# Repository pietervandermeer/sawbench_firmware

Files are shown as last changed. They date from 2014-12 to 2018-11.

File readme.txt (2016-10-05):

The Sawbench Synthesizer firmware.

(c) Tasty Chips Electronics, 2014-2016

This code may be used to update your sawbench synth, using only an Arduino Uno 
(10 euro from China). The easiest way of doing things is to: 

1) install this archive in your arduino folder. On Mac that's mostly 
~/Documents/Arduino

2) start Arduino IDE

3) open sawbench_v3/sawbench_v3.ino

4) attach your arduino uno

5) upload. The firmware is now present on the Arduino's Atmega328P. 

6) open up the sawbench, and remove its atmega. 

7) replace the sawbench's Atmega with the one from the Arduino. Presto!

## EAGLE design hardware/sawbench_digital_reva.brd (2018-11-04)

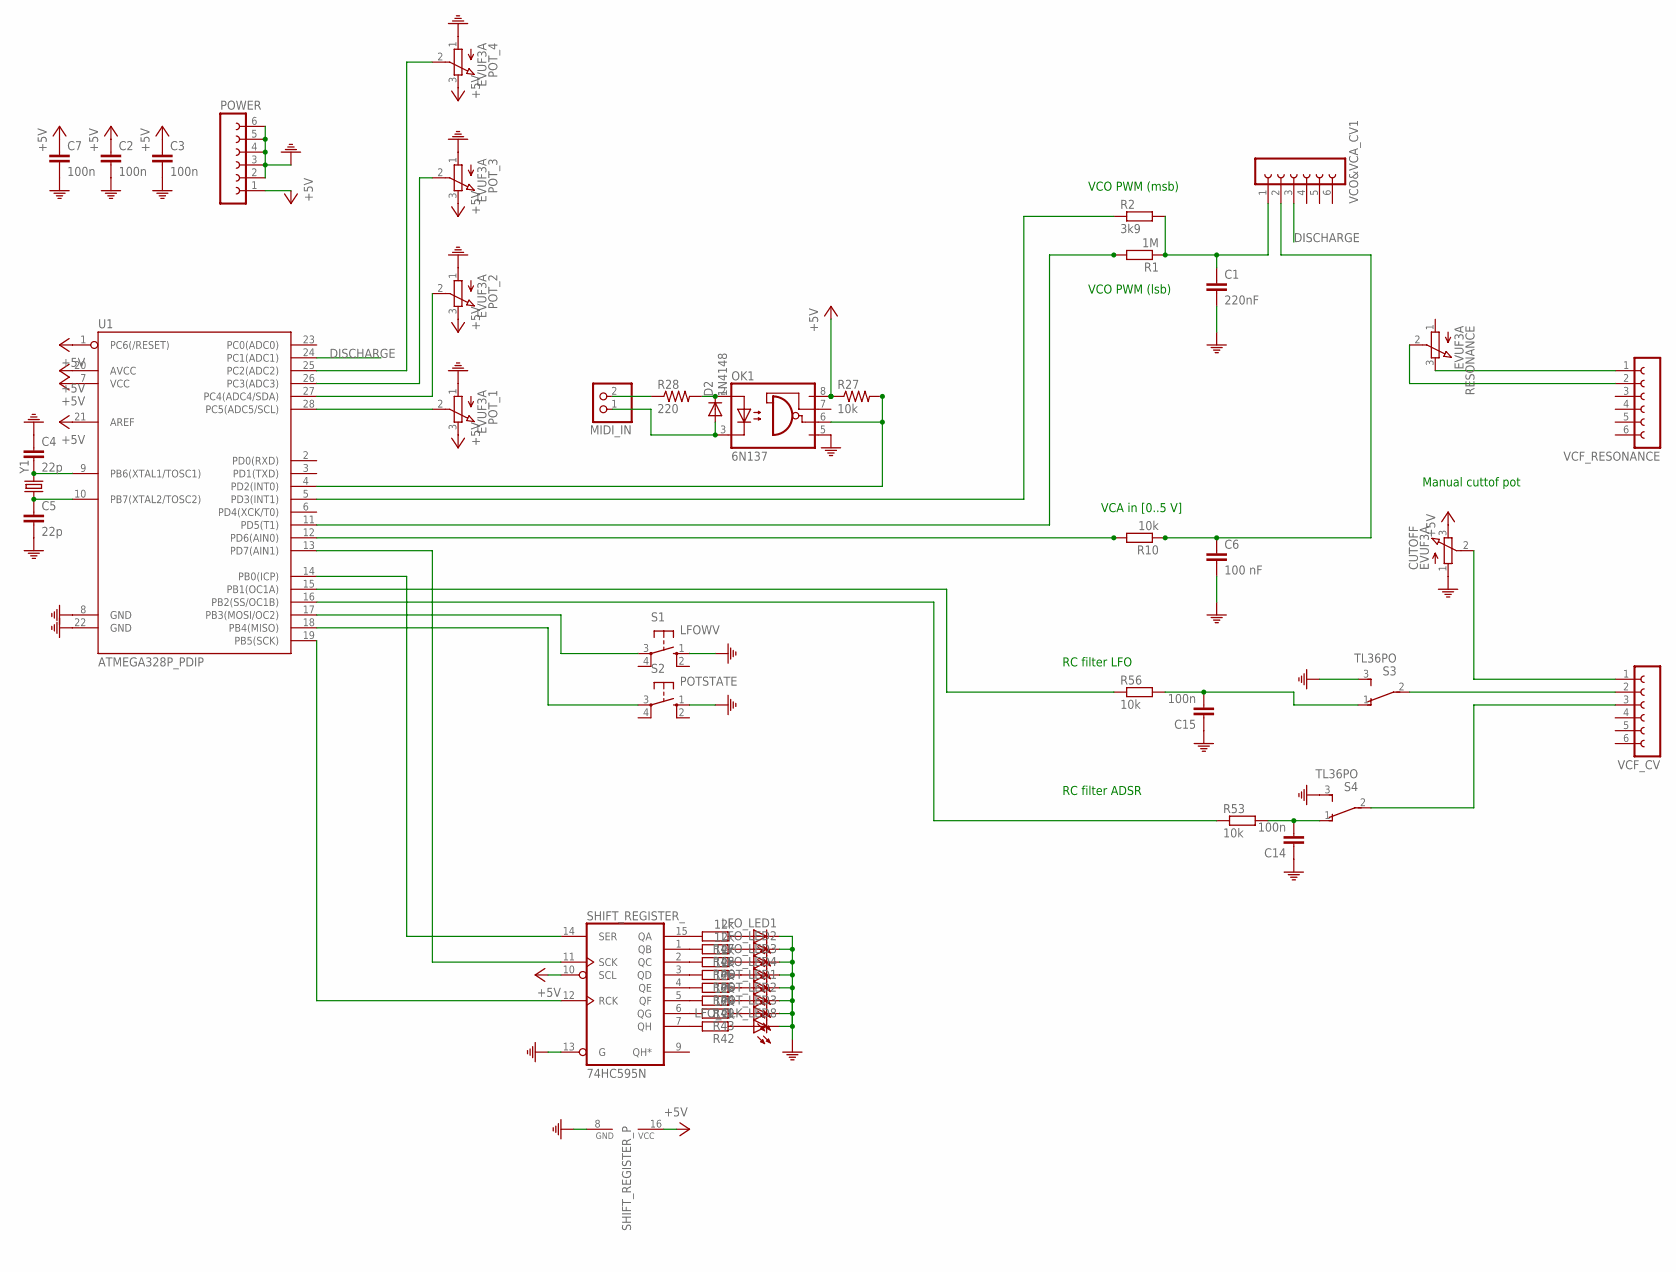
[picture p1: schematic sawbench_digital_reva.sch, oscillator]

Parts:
C1: 220nF; C050-024X044
C2, C3, C7, C14, C15: 100n; C025-024X044
C4, C5: 22p; C025-024X044
C6: 100 nF; C025-025X050
CUTOFF: EVUF3A; EVUF
D2: 1N4148; D-5
LFO_CLK_LED8: LED3MM
LFO_LED1, LFO_LED2, LFO_LED3, LFO_LED4: LED3MM
MIDI_IN: PINHD-1X2; 1X02
OK1: 6N137; DIL08
POT_1, POT_2, POT_3, POT_4: EVUF3A; EVUF
POT_LED1, POT_LED2, POT_LED3: LED3MM
POWER: FE06-1; FE06
R1: 1M; 0204/7
R2: 3k9; 0204/7
R10, R27, R53, R56: 10k; 0204/7
R28: 220; 0204/7
R42, R43, R44, R45, R46, R47, R48, R49: 12k; 0204/7
RESONANCE: EVUF3A; EVUF
S1: LFOWV; B3F-10XX(TASTYSWITCH)
S2: POTSTATE; B3F-10XX(TASTYSWITCH)
S3, S4: TL36PO; TL3XPO(TASTY_CHIPS_UPDATE)
SHIFT_REGISTER_: 74HC595N; DIL16
U1: ATMEGA328P_PDIP; DIL28-3
VCF_CV: FE06-1; FE06
VCF_RESONANCE: FE06-1; FE06
VCO&VCA_CV1: FE06-1; FE06
Y1: CRYSTALHC49S; HC49/S

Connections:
+5V: C2.1, C3.1, C7.1, CUTOFF.3 (E), OK1.8 (VCC), POT_1.3 (E), POT_2.3 (E), POT_3.3 (E), POT_4.3 (E), POWER.1, R27.1, SHIFT_REGISTER_.10 (SCL), SHIFT_REGISTER_.16 (VCC), U1.1 (PC6(/RESET)), U1.7 (VCC), U1.20 (AVCC), U1.21 (AREF)
DISCHARGE: U1.24 (PC1(ADC1)), VCO&VCA_CV1.3
unnamed: C1.1, R1.1, R2.2, VCO&VCA_CV1.1
unnamed: C6.1, R10.1, VCO&VCA_CV1.2
unnamed: R1.2, U1.11 (PD5(T1))
unnamed: S3.2, VCF_CV.2
unnamed: S4.2, VCF_CV.3
unnamed: OK1.6 (VO), R27.2, U1.4 (PD2(INT0))
unnamed: R2.1, U1.5 (PD3(INT1))
unnamed: POT_1.2 (S), U1.28 (PC5(ADC5/SCL))
unnamed: POT_4.2 (S), U1.25 (PC2(ADC2))
unnamed: POT_2.2 (S), U1.27 (PC4(ADC4/SDA))
unnamed: SHIFT_REGISTER_.11 (SCK), U1.13 (PD7(AIN1))
unnamed: POT_3.2 (S), U1.26 (PC3(ADC3))
unnamed: S1.3, U1.17 (PB3(MOSI/OC2))
unnamed: C4.2, U1.9 (PB6(XTAL1/TOSC1)), Y1.2
unnamed: C5.1, U1.10 (PB7(XTAL2/TOSC2)), Y1.1
unnamed: R10.2, U1.12 (PD6(AIN0))
unnamed: CUTOFF.2 (S), VCF_CV.1
unnamed: D2.C, OK1.2 (A), R28.2
unnamed: MIDI_IN.2, R28.1
unnamed: LFO_LED1.A, R47.1
unnamed: RESONANCE.3 (E), VCF_RESONANCE.1
unnamed: C14.2, R53.2, S4.1 (O)
unnamed: R42.2, SHIFT_REGISTER_.7 (QH)
unnamed: R43.2, SHIFT_REGISTER_.6 (QG)
unnamed: R44.2, SHIFT_REGISTER_.4 (QE)
unnamed: R45.2, SHIFT_REGISTER_.3 (QD)
unnamed: R46.2, SHIFT_REGISTER_.2 (QC)
unnamed: R47.2, SHIFT_REGISTER_.15 (QA)
unnamed: R48.2, SHIFT_REGISTER_.1 (QB)
unnamed: R49.2, SHIFT_REGISTER_.5 (QF)
unnamed: LFO_LED2.A, R48.1
unnamed: LFO_LED3.A, R46.1
unnamed: LFO_LED4.A, R45.1
unnamed: POT_LED1.A, R44.1
unnamed: POT_LED2.A, R49.1
unnamed: POT_LED3.A, R43.1
unnamed: LFO_CLK_LED8.A, R42.1
unnamed: SHIFT_REGISTER_.12 (RCK), U1.19 (PB5(SCK))
unnamed: SHIFT_REGISTER_.14 (SER), U1.14 (PB0(ICP))
unnamed: S2.3, U1.18 (PB4(MISO))
unnamed: C15.2, R56.2, S3.1 (O)
unnamed: R56.1, U1.15 (PB1(OC1A))
unnamed: R53.1, U1.16 (PB2(SS/OC1B))
unnamed: RESONANCE.2 (S), VCF_RESONANCE.2
unnamed: D2.A, MIDI_IN.1, OK1.3 (C)
PE: C1.2, C2.2, C3.2, C4.1, C5.2, C6.2, C7.2, C14.1, C15.1, CUTOFF.1 (A), LFO_CLK_LED8.K (C), LFO_LED1.K (C), LFO_LED2.K (C), LFO_LED3.K (C), LFO_LED4.K (C), OK1.5 (GND), POT_1.1 (A), POT_2.1 (A), POT_3.1 (A), POT_4.1 (A), POT_LED1.K (C), POT_LED2.K (C), POT_LED3.K (C), POWER.2, POWER.3, POWER.4, POWER.5, POWER.6, S1.1 (S), S2.1 (S), S3.3 (S), S4.3 (S), SHIFT_REGISTER_.8 (GND), SHIFT_REGISTER_.13 (G), U1.8 (GND), U1.22 (GND)

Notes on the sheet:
VCO PWM (msb)
VCO PWM (lsb)
VCA in [0..5 V]
RC filter LFO
RC filter ADSR
Manual cuttof pot

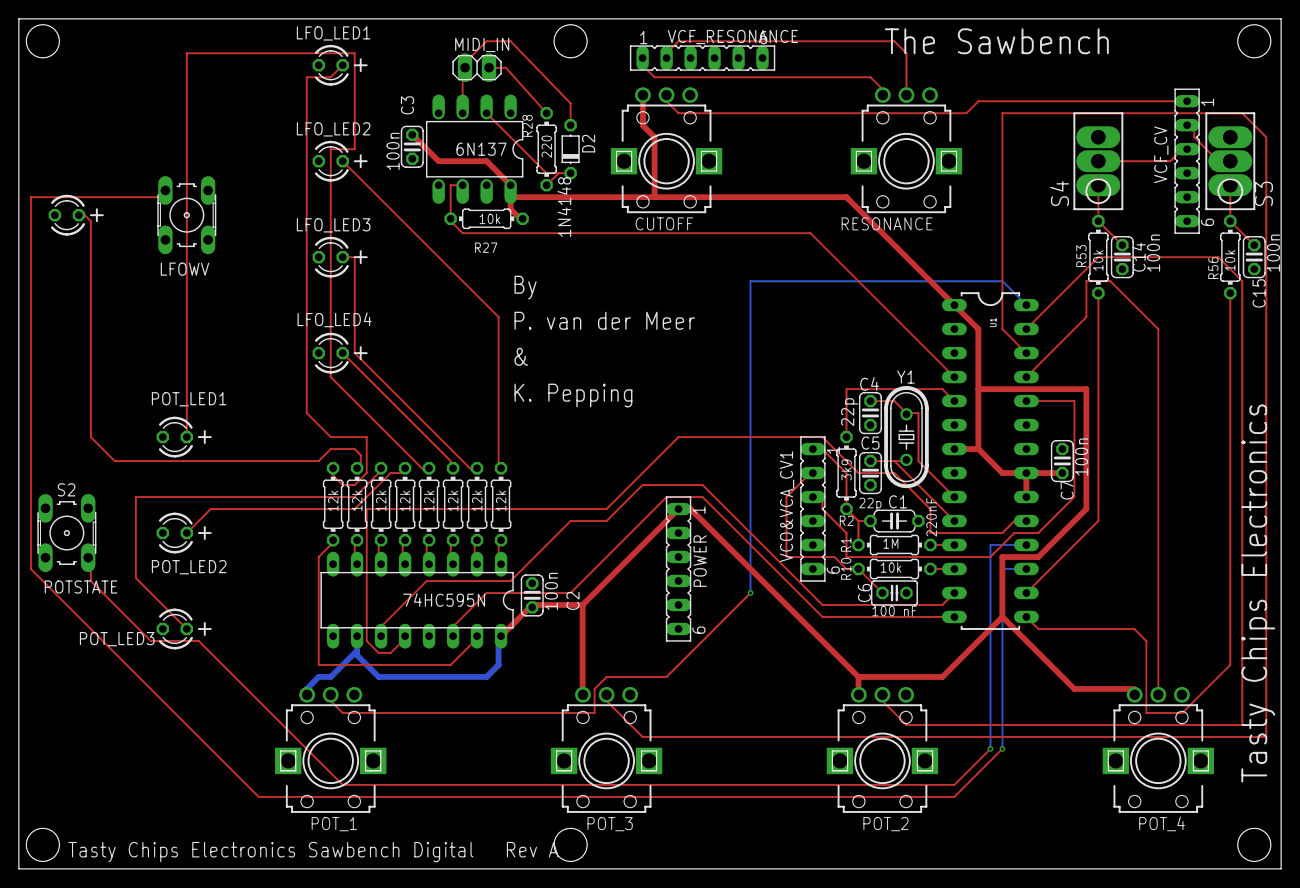
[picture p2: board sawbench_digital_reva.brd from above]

Board: 2 copper layers, 133.7 x 90.0 mm, 52 parts (0 on the bottom side), 48 nets.

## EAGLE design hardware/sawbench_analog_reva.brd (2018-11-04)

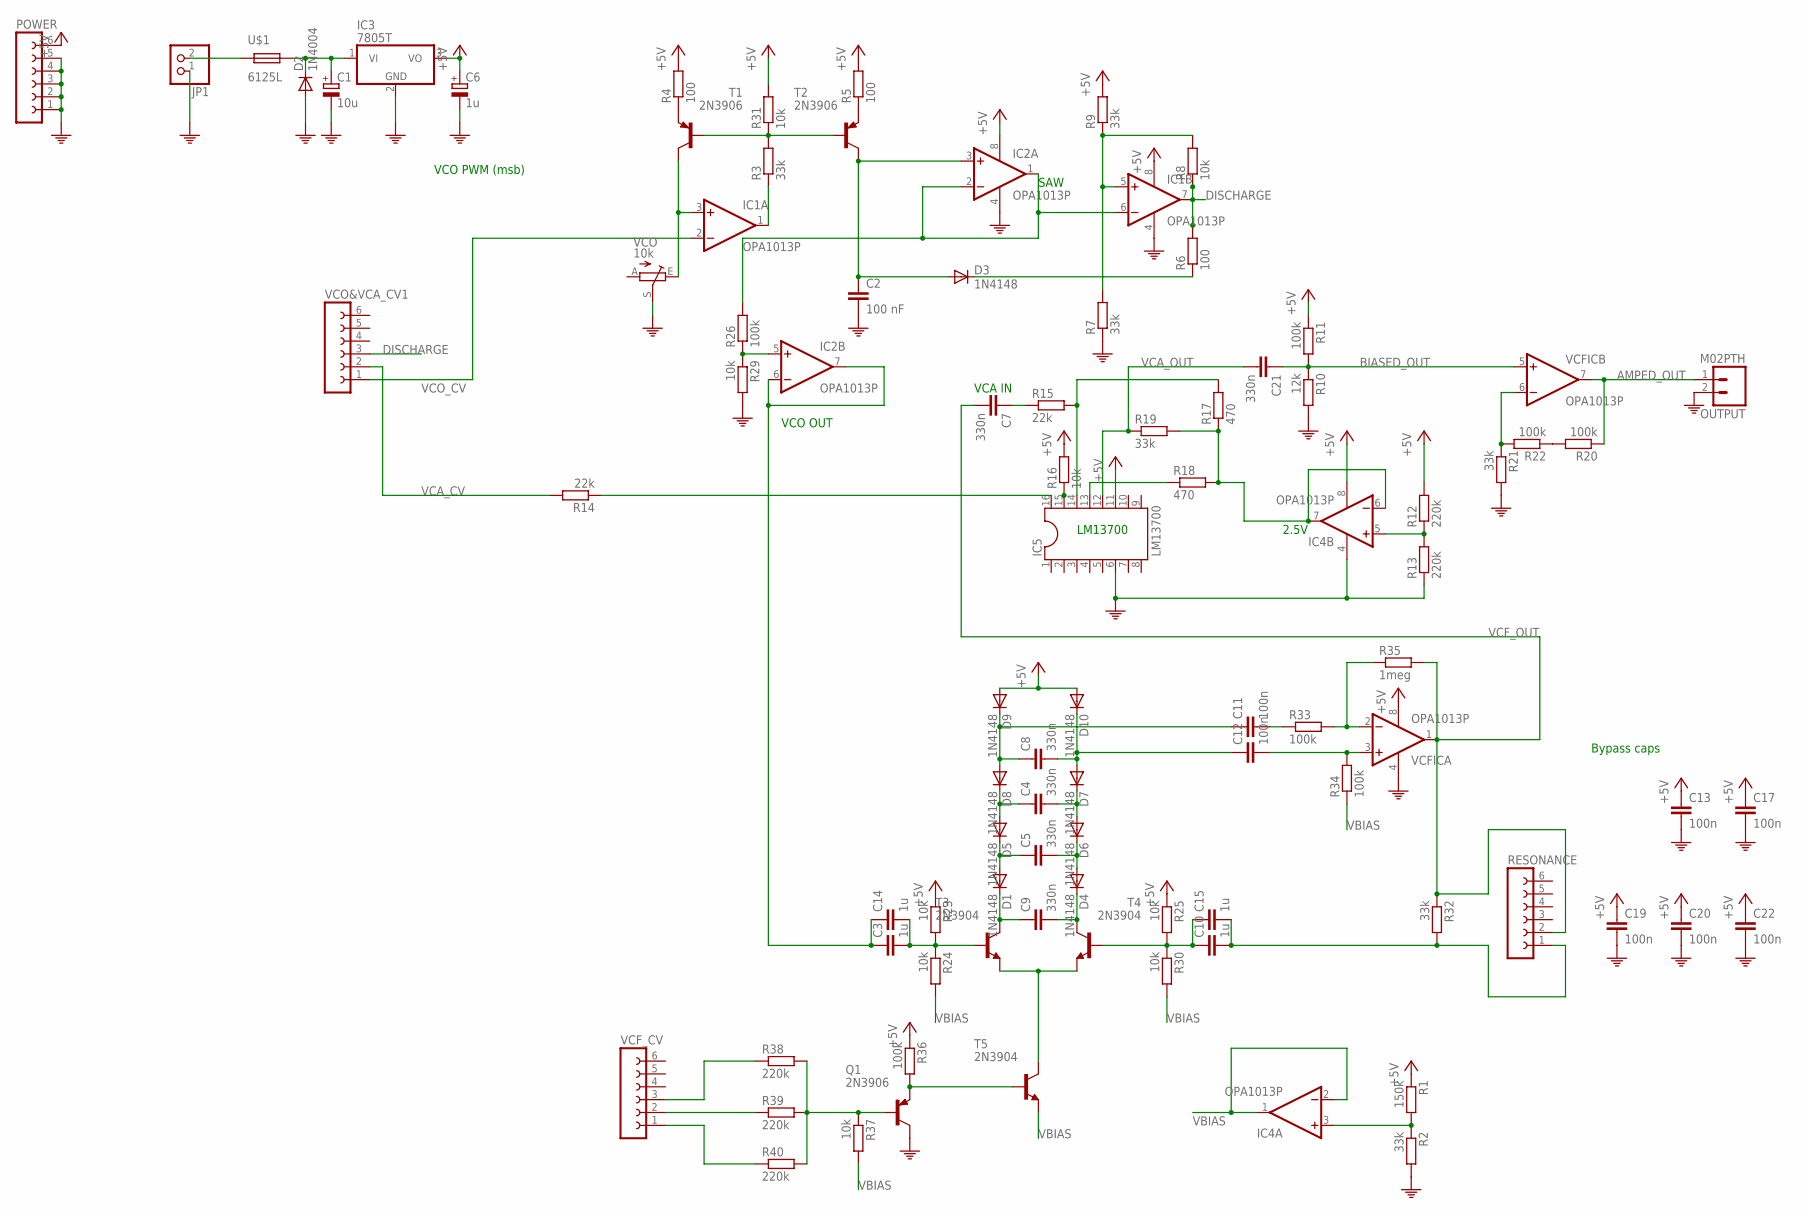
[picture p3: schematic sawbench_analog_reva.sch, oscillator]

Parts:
C1: 10u; E2,5-6
C2: 100 nF; C050-030X075
C3, C10, C14, C15: 1u; C050-024X044
C4, C5, C8, C9: 330n; C050-030X075
C6: 1u; E2,5-6
C7, C21: 330n; C050-024X044
C11, C12: 100n; C050-025X075
C13, C17, C19, C20, C22: 100n; C025-024X044
D1, D3, D4, D5, D6, D7, D8, D9, D10: 1N4148; D-5
D2: 1N4004; DO41-10
IC1, IC2, IC4: OPA1013P; DIL08
IC3: 7805T; TO220H
IC5: LM13700; DIL16
JP1: PINHD-1X2; 1X02
OUTPUT: M02PTH; 1X02
POWER: FE06-1; FE06
Q1: 2N3906; TO92-EBC
R1: 150k; 0204/7
R2, R3, R7, R9, R19, R21, R32: 33k; 0204/7
R4, R5, R6: 100; 0204/7
R8, R16, R23, R24, R25, R29, R30, R31, R37: 10k; 0204/7
R10: 12k; 0204/7
R11, R20, R22, R26, R33, R34, R36: 100k; 0204/7
R12, R13, R38, R39, R40: 220k; 0204/7
R14, R15: 22k; 0204/7
R17, R18: 470; 0204/7
R35: 1meg; 0204/7
RESONANCE: FE06-1; FE06
T1, T2: 2N3906; TO92-EBC
T3, T4, T5: 2N3904; TO92-EBC
U$1: 6125L
VCFIC: OPA1013P; DIL08
VCF_CV: FE06-1; FE06
VCO: 10k; RJ9W
VCO&VCA_CV1: FE06-1; FE06

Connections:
+5V: C6.+, C13.1, C17.1, C19.1, C20.1, C22.1, D9.A, D10.A, IC1.8 (V+), IC2.8 (V+), IC3.3 (VO), IC4.8 (V+), IC5.11, POWER.6, R1.1, R4.2, R5.2, R9.2, R11.1, R12.2, R16.2, R23.1, R25.1, R31.2, R36.1, VCFIC.8 (V+)
AMPED_OUT: OUTPUT.1, R20.1, VCFIC.7 (OUT)
BIASED_OUT: C21.1, R10.1, R11.2, VCFIC.5 (+IN)
DISCHARGE: IC1.7 (OUT), R6.2, R8.1, VCO&VCA_CV1.3
unnamed: R20.2, R22.1
unnamed: IC1.3 (+IN), T1.C, VCO.E
unnamed: C3.1, C14.1, IC2.6 (-IN), IC2.7 (OUT)
unnamed: C2.1, D3.A, IC2.3 (+IN), T2.C
unnamed: IC1.1 (OUT), R3.1
unnamed: R3.2, R31.1, T1.B, T2.B
unnamed: R4.1, T1.E
unnamed: R5.1, T2.E
unnamed: IC5.16, R14.1
unnamed: IC1.6 (-IN), IC2.1 (OUT), IC2.2 (-IN), R26.2
unnamed: R40.1, VCF_CV.1
unnamed: R39.1, VCF_CV.2
unnamed: IC1.5 (+IN), R7.2, R8.2, R9.1
unnamed: JP1.2, U$1.P$1 (1)
unnamed: D3.C, R6.1
unnamed: R38.1, VCF_CV.3
unnamed: IC4.3 (+IN), R1.2, R2.1
unnamed: IC4.5 (+IN), R12.1, R13.2
unnamed: IC5.13, R18.1
unnamed: IC5.14, R15.2, R17.2
unnamed: IC5.15, R16.1
unnamed: R21.1, R22.2, VCFIC.6 (-IN)
unnamed: IC4.6 (-IN), IC4.7 (OUT), R17.1, R18.2, R19.2
unnamed: C3.2, C14.2, R23.2, R24.1, T3.B
unnamed: T3.E, T4.E, T5.C
unnamed: C9.1, D1.C, T3.C
unnamed: C9.2, D4.C, T4.C
unnamed: C5.1, D1.A, D5.C
unnamed: C1.+, D2.C, IC3.1 (VI), U$1.P$2 (2)
unnamed: IC2.5 (+IN), R26.1, R29.1
unnamed: C7.1, R15.1
unnamed: C4.1, D5.A, D8.C
unnamed: C8.1, C11.1, D8.A, D9.C
unnamed: C8.2, C12.1, D7.A, D10.C
unnamed: C4.2, D6.A, D7.C
unnamed: C5.2, D4.A, D6.C
unnamed: C10.1, C15.1, R25.2, R30.1, T4.B
unnamed: C10.2, C15.2, R32.2, RESONANCE.1
unnamed: C11.2, R33.1
unnamed: C12.2, R34.2, VCFIC.3 (+IN)
unnamed: R33.2, R35.1, VCFIC.2 (-IN)
unnamed: Q1.E, R36.2, T5.B
unnamed: Q1.B, R37.1, R38.2, R39.2, R40.2
PE: C1.-, C2.2, C6.-, C13.2, C17.2, C19.2, C20.2, C22.2, D2.A, IC1.4 (V-), IC2.4 (V-), IC3.2 (GND), IC4.4 (V-), IC5.6, JP1.1, OUTPUT.2, POWER.1, POWER.2, POWER.3, POWER.4, POWER.5, Q1.C, R2.2, R7.1, R10.2, R13.1, R21.2, R29.2, VCFIC.4 (V-), VCO.S
VBIAS: IC4.1 (OUT), IC4.2 (-IN), R24.2, R30.2, R34.1, R37.2, T5.E
VCA_CV: R14.2, VCO&VCA_CV1.2
VCA_OUT: C21.2, IC5.12, R19.1
VCF_OUT: C7.2, R32.1, R35.2, RESONANCE.2, VCFIC.1 (OUT)
VCO_CV: IC1.2 (-IN), VCO&VCA_CV1.1

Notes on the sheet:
VCO PWM (msb)
SAW
LM13700
2.5V
VCO OUT
VCA IN
Bypass caps

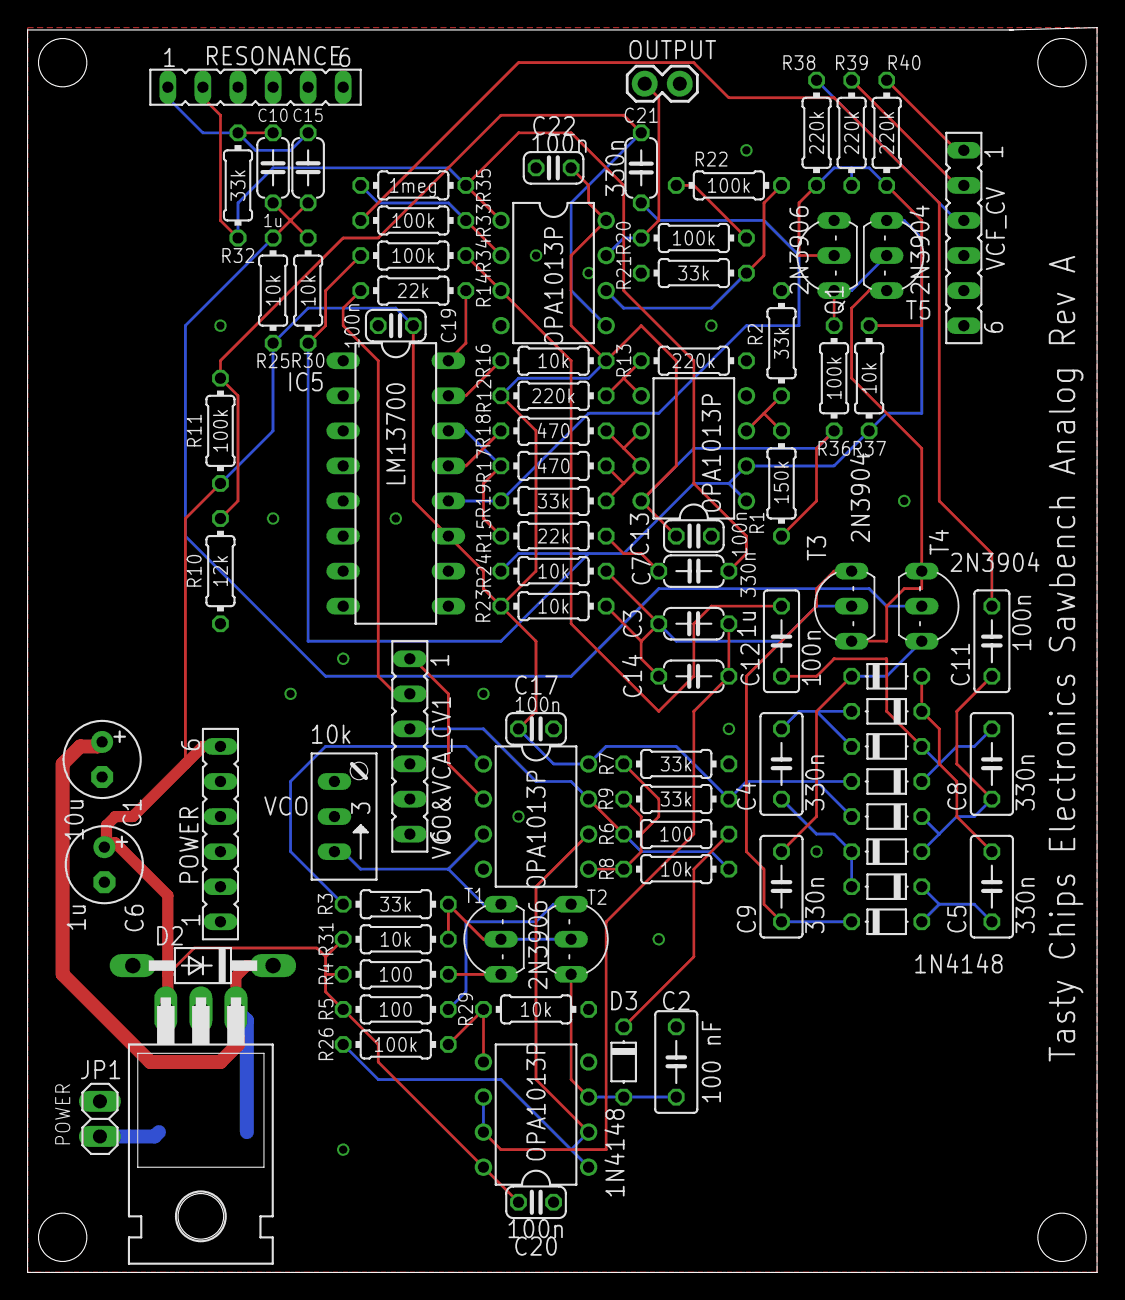
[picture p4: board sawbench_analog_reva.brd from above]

Board: 2 copper layers, 77.5 x 90.2 mm, 88 parts (1 on the bottom side), 53 nets.

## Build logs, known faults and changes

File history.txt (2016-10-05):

v1.0 apr 2015, initial version

v1.1 jul 2015, fixes midi buffer overflow, noticable with big bursts of data, for instance having a lot of automations in your DAW.. 

v1.2 oct 2016, faster attacks, exponential envelopes, tolerant to midi beat clock packets.

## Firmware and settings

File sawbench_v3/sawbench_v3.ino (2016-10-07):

// Sawbench firmware main sketch. v1.2

// defining this leaves in all debug statements.. logically, only for debugging ;) if you leave it on it causes serious delays to the main loop!
//#define DEBUG

#ifdef DEBUG
#define debug(args...) Serial.print(args)
#define debugln(args...) Serial.println(args)
#else
#define debug(args...) 
#define debugln(args...) 
#endif

#include <stdint.h>
#include <Statemachine.h>
#include <SimpleEnvelope.h>
#include <FrequencyModulator.h>
#include <Vco.h>
#include <PiggyLFO.h>
#include <Buttonscroll.h>
#include <Potstates.h>
#include <Writeregisters.h>

//Button + LED's
//===================================================
Writeregister writeregister1;
uint32_t loopCount;

Button buttonPOT(&loopCount, 0);
Button buttonLFO(&loopCount, 1);

Potstates POT1;
Potstates POT2;
Potstates POT3;
Potstates POT4;

int Pot1Value;
int Pot2Value;
int Pot3Value;
int Pot4Value;

unsigned char  potMax = 3; // nr of pot states
unsigned char  LFOmax = 4; // nr of lfo waveforms
unsigned char  pot_button_state;
unsigned char  lfo_button_state;
unsigned char  minimum_button_time;
unsigned char pot_index;
unsigned char  lfo_index;
bool lfoLedEnabled = true;

//LFO
//===================================================
uint16_t lfoCounter;
uint16_t lfoSpeed;
unsigned char lfoOutput;
LFO LFO1;

//PINS
//===================================================
const unsigned char LFOpin = 9;
const unsigned char DS_PIN = 8;     // Serial port input 74HC595
const unsigned char SHCP_PIN = 7; // Shift clock input 74HC595
const unsigned char STCP_PIN = 13; // storage clock input 74HC595
const unsigned char LFO_BUTTON = 11;  
const unsigned char POT_BUTTON = 12;

const unsigned char POT_4 = A2; //R1 + R2 + ADSR_2_AMOUNT
const unsigned char POT_3 = A4; //S1 + S2 + ADSR_1_AMOUNT
const unsigned char POT_2 = A3; //D1 + D2 + LFO_AMOUNT
const unsigned char POT_1 = A5; //A1 + A2 + LFO_SPEED
//===================================================

#define ADSR_TICKLEN 64 // ms/64

const unsigned char midi_in_pin = 2;       // digital pin nr on which you can read the MIDI in signal
const unsigned char vco_ms_pwm = 3;        // most significant VCO pwm pin
const unsigned char vco_ls_pwm = 5;        // least significant VCO pwm pin
const unsigned char saw_vca_pwm = 6;       // envelope control (VCA) pwm pin, for saw signal
const unsigned char vco_mode_input_pin = 7;
const unsigned char vcf_pwm_pin = 10;

Midi::Statemachine midi_sm;
int32_t fm_amp;
int8_t cosLut[] = {127,127,127,127,127,126,126,126,125,124,124,123,122,121,120,119,118,116,115,114,112,111,109,108,106,104,102,100,98,96,94,92,90,88,85,83,81,78,76,73,71,68,65,63,60,57,54,51,48,46,43,40,37,34,31,28,24,21,18,15,12,9,6,3,0,-3,-6,-9,-12,-15,-18,-21,-24,-28,-31,-34,-37,-40,-43,-46,-48,-51,-54,-57,-60,-63,-65,-68,-71,-73,-76,-78,-81,-83,-85,-88,-90,-92,-94,-96,-98,-100,-102,-104,-106,-108,-109,-111,-112,-114,-115,-116,-118,-119,-120,-121,-122,-123,-124,-124,-125,-126,-126,-126,-127,-127,-127,-127,-127,-127,-127,-127,-127,-126,-126,-126,-125,-124,-124,-123,-122,-121,-120,-119,-118,-116,-115,-114,-112,-111,-109,-108,-106,-104,-102,-100,-98,-96,-94,-92,-90,-88,-85,-83,-81,-78,-76,-73,-71,-68,-65,-63,-60,-57,-54,-51,-48,-46,-43,-40,-37,-34,-31,-28,-24,-21,-18,-15,-12,-9,-6,-3,0,3,6,9,12,15,18,21,24,28,31,34,37,40,43,46,48,51,54,57,60,63,65,68,71,73,76,78,81,83,85,88,90,92,94,96,98,100,102,104,106,108,109,111,112,114,115,116,118,119,120,121,122,123,124,124,125,126,126,126,127,127,127,127};
SignalControl::FrequencyModulator fm(&micros, 230, 16000000/ADSR_TICKLEN/64);
SimpleEnvelope envVca;
SimpleEnvelope envVcf;
Vco vco(vco_ms_pwm, vco_ls_pwm);

//-------------------------------------------------------------------------------------------
// electronics control
//-------------------------------------------------------------------------------------------

/*
 * Divides a given PWM pin frequency by a divisor.
 * 
 * The resulting frequency is equal to the base frequency divided by
 * the given divisor:
 *   - Base frequencies:
 *      o The base frequency for pins 3, 9, 10, and 11 is 31250 Hz.
 *      o The base frequency for pins 5 and 6 is 62500 Hz.
 *   - Divisors:
 *      o The divisors available on pins 5, 6, 9 and 10 are: 1, 8, 64,
 *        256, and 1024.
 *      o The divisors available on pins 3 and 11 are: 1, 8, 32, 64,
 *        128, 256, and 1024.
 * 
 * PWM frequencies are tied together in pairs of pins. If one in a
 * pair is changed, the other is also changed to match:
 *   - Pins 5 and 6 are paired on timer0
 *   - Pins 9 and 10 are paired on timer1
 *   - Pins 3 and 11 are paired on timer2
 * 
 * Note that this function will have side effects on anything else
 * that uses timers:
 *   - Changes on pins 3, 5, 6, or 11 may cause the delay() and
 *     millis() functions to stop working. Other timing-related
 *     functions may also be affected.
 *   - Changes on pins 9 or 10 will cause the Servo library to function
 *     incorrectly.
 * 
 * Thanks to macegr of the Arduino forums for his documentation of the
 * PWM frequency divisors. His post can be viewed at:
 *   http://www.arduino.cc/cgi-bin/yabb2/YaBB.pl?num=1235060559/0#4
 */
void setPwmFrequency(int pin, int divisor) {
  byte mode;
  if(pin == 5 || pin == 6 || pin == 9 || pin == 10) {
    switch(divisor) {
    case 1: 
      mode = 0x01; 
      break;
    case 8: 
      mode = 0x02; 
      break;
    case 64: 
      mode = 0x03; 
      break;
    case 256: 
      mode = 0x04; 
      break;
    case 1024: 
      mode = 0x05; 
      break;
    default: 
      return;
    }
    if(pin == 5 || pin == 6) {
      TCCR0B = (TCCR0B & 0b11111000) | mode;
    } 
    else {
      TCCR1B = (TCCR1B & 0b11111000) | mode;
    }
  } 
  else if(pin == 3 || pin == 11) {
    switch(divisor) {
    case 1: 
      mode = 0x01; 
      break;
    case 8: 
      mode = 0x02; 
      break;
    case 32: 
      mode = 0x03; 
      break;
    case 64: 
      mode = 0x04; 
      break;
    case 128: 
      mode = 0x05; 
      break;
    case 256: 
      mode = 0x06; 
      break;
    case 1024: 
      mode = 0x7; 
      break;
    default: 
      return;
    }
    TCCR2B = (TCCR2B & 0b11111000) | mode;
  }
}

void setVcaAttack(int v)
{
  envVca.setAttack(v/8);
}

void setVcaRelease(int v)
{
  envVca.setRelease(v/8);
}

void setVcaDecay(int v)
{
  envVca.setDecay(v/8);
}

void setVcaSustainLevel(int v)
{
  envVca.setSustainLevel(v/4);
}

void setVcfAttack(int v)
{
  envVcf.setAttack(v/8);
}

void setVcfRelease(int v)
{
  envVcf.setRelease(v/8);
}

void setVcfDecay(int v)
{
  envVcf.setDecay(v/8);
}

void setVcfSustainLevel(int v)
{
  envVcf.setSustainLevel(v/4);
}

void setLfoSpeed(int v)
{
  lfoSpeed = v;
  if (lfoSpeed < 8)
  {
    lfoSpeed = 8;
  }
}

uint8_t lfoAmount = 0;

void setLfoAmount(int v)
{
  lfoAmount = v/4;
}

uint8_t adsr1Amount=128, adsr2Amount = 128;

void setAdsr1Amount(int v)
{
  adsr1Amount = v/8;
}

void setAdsr2Amount(int v)
{
  adsr2Amount = v/8;
}

typedef enum
{
 controlchange_ctl_bankchange=0 // unused
,controlchange_ctl_modulation_wheel=1

// unused by the sawbench.. 
,controlchange_ctl_breath=2
,controlchange_ctl_undef=3
,controlchange_ctl_foot=4

,controlchange_ctl_effect1=0x0C // FM freq
,controlchange_ctl_effect2=0x0D // unused
,controlchange_ctl_sustainpedal=0x40 //unused
,controlchange_ctl_resonance=0x47
,controlchange_ctl_release=0x48 // 72
,controlchange_ctl_attack=0x49 // 73
,controlchange_ctl_brightness=0x4A
,controlchange_ctl_decay=0x4B // 75
,controlchange_ctl_sustain=0x50 // 80
,controlchange_ctl_vcf_release=0x54
,controlchange_ctl_vcf_attack=0x51
,controlchange_ctl_vcf_decay=0x52
,controlchange_ctl_vcf_sustain=0x53
,controlchange_ctl_lfo_speed=0x55
,controlchange_ctl_lfo_amount=0x56
,controlchange_ctl_adsr1_amount=0x57
,controlchange_ctl_adsr2_amount=0x58
,controlchange_ctl_lfo_type=0x5A // 90
// stuff that is not represented by on-board controls.. midi only:
,controlchange_ctl_vcf_tracking=0x59 // 89
,controlchange_ctl_glide_speed=0x5B // 91
,controlchange_ctl_legato=0x5C // 92
,controlchange_ctl_envloop=0x5D // 93
,controlchange_ctl_explin=0x5E // 94
// TODO: more!
} controlchange_controller_t;


uint8_t modulation_depth, effect1 = 27, vcfTracking = 64;
uint16_t glideSpeed = 127;
const uint16_t glideCountMax = 1024;

void midi_cc_callback(uint8_t cc, uint8_t val)
{
  debug("cc callback "); debug(cc); debugln(val);
  switch ((controlchange_controller_t) cc)
  {
    case controlchange_ctl_modulation_wheel:
      modulation_depth = val;
      break;
    case controlchange_ctl_effect1:
      // modulation frequency scalar 127 = .99 , 0 = 0!
      effect1 = val;
      break;
    case controlchange_ctl_brightness:
      // TODO: might be implemented someday.. but 7 bit is on the small side..
      break;
    case controlchange_ctl_attack:
      envVca.setAttack(val);
      break;
    case controlchange_ctl_decay:
      envVca.setDecay(val);
      break;
    case controlchange_ctl_sustain:
      envVca.setSustainLevel(val*2);
      break;
    case controlchange_ctl_release:
      envVca.setRelease(val);
      break;
    case controlchange_ctl_vcf_attack:
      envVcf.setAttack(val);
      break;
    case controlchange_ctl_vcf_decay:
      envVcf.setDecay(val);
      break;
    case controlchange_ctl_vcf_sustain:
      envVcf.setSustainLevel(val*2);
      break;
    case controlchange_ctl_vcf_release:
      envVcf.setRelease(val);
      break;
    case controlchange_ctl_lfo_speed:
      lfoSpeed = val*8;
      break;
    case controlchange_ctl_lfo_amount:
      lfoAmount = val*2;
      break;
    case controlchange_ctl_adsr1_amount:
      adsr1Amount = val;
      break;
    case controlchange_ctl_adsr2_amount:
      adsr2Amount = val;
      break;
    case controlchange_ctl_vcf_tracking:
      vcfTracking = val;
      break;
    case controlchange_ctl_lfo_type:
      if (val >= LFOmax)
      {
        val = LFOmax-1;
      }
      buttonLFO.scrollIndex = val;
      break;
    case controlchange_ctl_glide_speed:
      glideSpeed = (uint16_t) val;
      if (val == 127) 
      {
        glideSpeed = glideCountMax;
      }
      break;
    case controlchange_ctl_legato:
      midi_sm.setLegatoMode(val != 0);
      break;
    case controlchange_ctl_envloop:
      envVcf.setLooping(val&2);
      envVca.setLooping(val&1);
      break;
    case controlchange_ctl_explin:
      envVcf.setExpMode(val&2);
      envVca.setExpMode(val&1);
      break;
    default:
      break;
  }
}

int16_t lfoLedError;
bool lfoLed;

// the setup routine runs once when you press reset:
//===============================================================
void setup()  
{ 
  Serial.begin(115200);
  debugln(".");

  //
  // set parameter defaults
  //

  envVca.setAttack(0);
  envVca.setDecay(0);
  envVca.setSustainLevel(255);
  envVca.setRelease(10);

  envVcf.setAttack(0);
  envVcf.setDecay(40);
  envVcf.setSustainLevel(80);
  envVcf.setRelease(10);

  lfoSpeed = 8;
  lfoAmount = 255;
  adsr1Amount = 128;
  adsr2Amount = 128;

  //
  // initialize leds
  //
  
  // configure 595 pins
  writeregister1.ds_PIN = DS_PIN;
  writeregister1.shcp_PIN = SHCP_PIN;
  writeregister1.stcp_PIN = STCP_PIN;

  pinMode(DS_PIN, OUTPUT);
  pinMode(SHCP_PIN, OUTPUT);
  pinMode(STCP_PIN, OUTPUT);

  int del = 400;
  for (int i=0; i<34; i++)
  {
    writeregister1.LedWriter(4, lfo_index, pot_index, lfoLed);
    delay(del);
    lfo_index++;
    pot_index++;
    if (lfo_index > 3)
    {
      lfo_index = 0;
    }
    if (pot_index > 2)
    {
      pot_index = 0;
    }
    del *= 4;
    del /= 5;
  }

  //
  // calibrate vco (TODO: integrate with blinking leds)
  // 

  // Set pin PWM frequency to 62500 Hz (62500/1 = 62500)
  // Note that the base frequency for pins 5 and 6 is 62500 Hz
  setPwmFrequency(vco_ms_pwm, 1);
  setPwmFrequency(vco_ls_pwm, 1);

  vco.calibrate();

  fm.setLut(cosLut);

  pinMode(LFO_BUTTON, INPUT_PULLUP);
  pinMode(POT_BUTTON, INPUT_PULLUP);

  //POTS
  //========================================================
  pinMode(POT_4, INPUT);
  pinMode(POT_3, INPUT);
  pinMode(POT_2, INPUT);
  pinMode(POT_1, INPUT);

  // declare pwm pins to be outputs:
  pinMode(saw_vca_pwm, OUTPUT);
  pinMode(vcf_pwm_pin, OUTPUT);
  setPwmFrequency(vcf_pwm_pin, 1);
  setPwmFrequency(saw_vca_pwm, 1);

  vco.setType(Vco::VCO_TYPE_SAWBENCH);

  // silence, i kill u
  analogWrite(saw_vca_pwm, 0);
  
  //LFO 
  pinMode(LFOpin, OUTPUT);
  lfoCounter = 0;
  lfoOutput = 0;
  setPwmFrequency(LFOpin, 1);
  lfoSpeed = 100;

  midi_sm.register_cc_callback(midi_cc_callback);
  
  POT1.registerCallback(0, setVcaAttack);
  POT1.registerCallback(1, setVcfAttack);
  POT1.registerCallback(2, setLfoSpeed);
  POT2.registerCallback(0, setVcaDecay);
  POT2.registerCallback(1, setVcfDecay);
  POT2.registerCallback(2, setLfoAmount);
  POT3.registerCallback(0, setVcaSustainLevel);
  POT3.registerCallback(1, setVcfSustainLevel);
  POT3.registerCallback(2, setAdsr1Amount);
  POT4.registerCallback(0, setVcaRelease);
  POT4.registerCallback(1, setVcfRelease);
  POT4.registerCallback(2, setAdsr2Amount);

  lfoLedError = 0;
} 

//--

// actual synth engine variables 
uint16_t pitch = 0, old_pitch, synth_pitch;
uint16_t synth_velocity;

void synth_set_pitch()
{
  long pitch_bend; //fixedpoint
  pitch_bend = (long) (midi_sm.pitch_bend)  - 8192;
  pitch_bend *= pitch;
  pitch_bend >>= 16;
  synth_pitch = pitch + pitch_bend;
  debugln(synth_pitch);

  // directly set up the pitch and volume
  fm.setFreq(( (uint32_t) synth_pitch * (uint32_t) effect1 )>>7, 16000000/ADSR_TICKLEN/64);
}

//--

uint32_t lastTickTime;
uint16_t vca_amp, old_vca_amp;
uint16_t vcf_amp, old_vcf_amp;

uint16_t old_mod_pitch = 0;
uint8_t old_active_key;
uint16_t modulated_pitch;
uint16_t glideSetpoint, oldGlideSetpoint;
uint16_t glideCount;

// the loop routine runs over and over again forever:
//===================================================
void loop()
{

  // do the actual signal control first in order to eliminate jitter!
  vco.write(modulated_pitch);
  analogWrite(saw_vca_pwm, (vca_amp*synth_velocity)>>8);
  analogWrite(vcf_pwm_pin, vcf_amp + ((midi_sm.active_key * (uint16_t) vcfTracking)/64) );

  // handle midi state machine
  midi_sm.run();

  // a = (m*v+b)^2, v: midi velocity, m = 1-b, b = 126/(127*sqrt(range))
  synth_velocity = midi_sm.active_velocity+0x68;
  synth_velocity *= synth_velocity;
  synth_velocity = ((uint32_t) synth_velocity * (uint32_t) adsr1Amount) / 8192;

  // volume clipping
  if (synth_velocity > 255)
  {
    synth_velocity = 255;
  }
  if (old_active_key != midi_sm.active_key)
  {
    debugln("active key!");
    debugln(midi_sm.active_key);
    // start glide..
    oldGlideSetpoint = glideSetpoint;
    glideSetpoint = vco.getNotePitch(midi_sm.active_key);
    glideCount = 0;
  }
  old_active_key = midi_sm.active_key;

  // glide
  if (glideCount < glideCountMax)
  {
    glideCount += glideSpeed;
  }
  // clip glide to max
  if (glideCount > glideCountMax)
  {
    glideCount = glideCountMax;
  }
  pitch = ( ((uint32_t) oldGlideSetpoint * (glideCountMax-glideCount)) + ((uint32_t) glideSetpoint * glideCount) ) / glideCountMax;
  
  synth_set_pitch();

  // MIDI note on / note off -> envelope control
  if (midi_sm.triggered)
  {
    debugln("triggered");
    envVca.trigger();
    envVcf.trigger();
    midi_sm.triggered = false;
  }
  if (midi_sm.stopped)
  {
    debugln("stopped");
    envVca.stop();
    envVcf.stop();
    midi_sm.stopped = false;
  }
  
  //
  // update envelopes
  //

  if (loopCount&1)
  {
    envVca.run();
    vca_amp = envVca.output >> envVca.precision;
    if (vca_amp != old_vca_amp)
    {
      debug("vca = "); debugln((long)envVca.output);
      debug("vca = "); debugln(vca_amp);
    }
    old_vca_amp = vca_amp;
  }
  else
  {
    // update VCF envelope
    envVcf.run();
    vcf_amp = ((envVcf.output >> envVcf.precision) * adsr2Amount) /256;
    if (vcf_amp != old_vcf_amp)
    {
      debug("vcf = "); debugln(vcf_amp);
    }
    old_vcf_amp = vcf_amp;
  }

  // handle modulation
  fm_amp = effect1 ? (int32_t) fm.step() : 0;
  modulated_pitch =  ( ( ((fm_amp * (int32_t)synth_pitch)>>6) * (int32_t)(modulation_depth) ) >>8) + synth_pitch;
#ifdef DEBUG
  if (modulated_pitch != old_mod_pitch)
  {
    debugln(modulated_pitch);
    debug("fm_amp="); debug(fm_amp); debug(" midi modulation depth="); debugln(modulation_depth);
    old_mod_pitch = modulated_pitch;
  }
#endif
  //BUTTON + LED'S
  //=====================================================

  // round robin which pot to read, because analogRead() is very slow.. and we don't need to read out at 2 kHz.. 60 Hz is already ok.
  switch(loopCount%4)
  {
    case 0:
    Pot1Value = analogRead(POT_1);
    POT1.potStatesWrite(pot_index, Pot1Value);
    break;
    case 1:
    Pot2Value = analogRead(POT_2);
    POT2.potStatesWrite(pot_index, Pot2Value);
    break;
    case 2:
    POT3.potStatesWrite(pot_index, Pot3Value);
    Pot3Value = analogRead(POT_3);
    break;
    case 3:
    POT4.potStatesWrite(pot_index, Pot4Value);
    Pot4Value = analogRead(POT_4); 
    break;
  }
  
  pot_button_state = digitalRead(POT_BUTTON);
  lfo_button_state = digitalRead(LFO_BUTTON);
  
  unsigned char c;
  if ((c = buttonPOT.ButtonScroll(potMax, pot_button_state, minimum_button_time)) != 255)
  {
    pot_index = c;
  }
  if ((c = buttonLFO.ButtonScroll(LFOmax, lfo_button_state, minimum_button_time)) == 255)
  {
    lfoLedEnabled = !lfoLedEnabled; 
  }
  else
  {
    lfo_index = c;
  }

  if (lfoLedEnabled)
  {
    lfoLedError += lfoOutput - (lfoLed*256);
    lfoLed = (lfoLedError >= 128);
  }
  else
  {
    lfoLed = false;
  }

  writeregister1.LedWriter(4, lfo_index, pot_index, lfoLed);

  // step through
  lfoOutput = LFO1.LFOout(lfo_index, lfoCounter/256);
  //Serial.print(lfoCounter/256, HEX); Serial.print(" "); Serial.println(lfoOutput, HEX);
  analogWrite(LFOpin, ((uint16_t) lfoOutput * (uint16_t) lfoAmount)/256);
  lfoCounter += lfoSpeed;
  //=====================================================

  loopCount++;

  // 
  // wait until we get a precisely timed loop..
  //
  
  uint32_t tickTime;
  do {
    tickTime = micros();
  } while(tickTime - lastTickTime < ADSR_TICKLEN*1000UL);
  lastTickTime = tickTime;  

}

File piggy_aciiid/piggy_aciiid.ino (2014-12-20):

#define CLEAR_TRANSIENTS 1

#include <stdint.h>
#include <Envelope.h>
#include <Vco.h>
#include <FrequencyModulator.h>

// one 'tick' : length of 1/64 note in number of PWM periods
#define TICKLEN 900 // 900 FOR SONG, 880 FOR SONG2, 1060 FOR SONG3
#define ADSR_TICKLEN 30

const int midi_in_pin = 2;       // digital pin nr on which you can read the MIDI in signal
const int vco_ms_pwm = 3;           // most significant VCO pwm pin
const int vco_ls_pwm = 5;           // least significant VCO pwm pin
const int saw_vca_pwm = 6;          // envelope control (VCA) pwm pin, for saw signal
const int vco_mode_input_pin = 7;
const int adsr_mode_input_pin = 8;
const int vco_mode_led = 9;
const int adsr_mode_led = 10;
const int square_vca_pwm = 11;          // envelope control (VCA) pvm pin, for square/pwm signal

unsigned short pitch0, pitch, pitch2; // pitch of: lower neighbour note, actual note, higher neighbour note    

#define NOTE_OCTAVE 12

#define NOTE_C0 0
#define NOTE_CS0 1
#define NOTE_D0 2
#define NOTE_DS0 3
#define NOTE_E0 4
#define NOTE_F0 5
#define NOTE_FS0 6
#define NOTE_G0 7
#define NOTE_GS0 8
#define NOTE_A0 9
#define NOTE_AS0 10
#define NOTE_B0 11

#define NOTE_C1 (NOTE_C0 + NOTE_OCTAVE*1)
#define NOTE_CS1 (NOTE_CS0 + NOTE_OCTAVE*1)
#define NOTE_D1 (NOTE_D0 + NOTE_OCTAVE*1)
#define NOTE_DS1 (NOTE_DS0 + NOTE_OCTAVE*1)
#define NOTE_E1 (NOTE_E0 + NOTE_OCTAVE*1)
#define NOTE_F1 (NOTE_F0 + NOTE_OCTAVE*1)
#define NOTE_FS1 (NOTE_FS0 + NOTE_OCTAVE*1)
#define NOTE_G1 (NOTE_G0 + NOTE_OCTAVE*1)
#define NOTE_GS1 (NOTE_GS0 + NOTE_OCTAVE*1)
#define NOTE_A1 (NOTE_A0 + NOTE_OCTAVE*1)
#define NOTE_AS1 (NOTE_AS0 + NOTE_OCTAVE*1)
#define NOTE_B1 (NOTE_B0 + NOTE_OCTAVE*1)

#define NOTE_C2 (NOTE_C0 + NOTE_OCTAVE*2)
#define NOTE_CS2 (NOTE_CS0 + NOTE_OCTAVE*2)
#define NOTE_D2 (NOTE_D0 + NOTE_OCTAVE*2)
#define NOTE_DS2 (NOTE_DS0 + NOTE_OCTAVE*2)
#define NOTE_E2 (NOTE_E0 + NOTE_OCTAVE*2)
#define NOTE_F2 (NOTE_F0 + NOTE_OCTAVE*2)
#define NOTE_FS2 (NOTE_FS0 + NOTE_OCTAVE*2)
#define NOTE_G2 (NOTE_G0 + NOTE_OCTAVE*2)
#define NOTE_GS2 (NOTE_GS0 + NOTE_OCTAVE*2)
#define NOTE_A2 (NOTE_A0 + NOTE_OCTAVE*2)
#define NOTE_AS2 (NOTE_AS0 + NOTE_OCTAVE*2)
#define NOTE_B2 (NOTE_B0 + NOTE_OCTAVE*2)

#define NOTE_C3 (NOTE_C0 + NOTE_OCTAVE*3)
#define NOTE_CS3 (NOTE_CS0 + NOTE_OCTAVE*3)
#define NOTE_D3 (NOTE_D0 + NOTE_OCTAVE*3)
#define NOTE_DS3 (NOTE_DS0 + NOTE_OCTAVE*3)
#define NOTE_E3 (NOTE_E0 + NOTE_OCTAVE*3)
#define NOTE_F3 (NOTE_F0 + NOTE_OCTAVE*3)
#define NOTE_FS3 (NOTE_FS0 + NOTE_OCTAVE*3)
#define NOTE_G3 (NOTE_G0 + NOTE_OCTAVE*3)
#define NOTE_GS3 (NOTE_GS0 + NOTE_OCTAVE*3)
#define NOTE_A3 (NOTE_A0 + NOTE_OCTAVE*3)
#define NOTE_AS3 (NOTE_AS0 + NOTE_OCTAVE*3)
#define NOTE_B3 (NOTE_B0 + NOTE_OCTAVE*3)

#define NOTE_C4 (NOTE_C0 + NOTE_OCTAVE*4)
#define NOTE_CS4 (NOTE_CS0 + NOTE_OCTAVE*4)
#define NOTE_D4 (NOTE_D0 + NOTE_OCTAVE*4)
#define NOTE_DS4 (NOTE_DS0 + NOTE_OCTAVE*4)
#define NOTE_E4 (NOTE_E0 + NOTE_OCTAVE*4)
#define NOTE_F4 (NOTE_F0 + NOTE_OCTAVE*4)
#define NOTE_FS4 (NOTE_FS0 + NOTE_OCTAVE*4)
#define NOTE_G4 (NOTE_G0 + NOTE_OCTAVE*4)
#define NOTE_GS4 (NOTE_GS0 + NOTE_OCTAVE*4)
#define NOTE_A4 (NOTE_A0 + NOTE_OCTAVE*4)
#define NOTE_AS4 (NOTE_AS0 + NOTE_OCTAVE*4)
#define NOTE_B4 (NOTE_B0 + NOTE_OCTAVE*4)

#define NOTE_C5 (NOTE_C0 + NOTE_OCTAVE*5)
#define NOTE_CS5 (NOTE_CS0 + NOTE_OCTAVE*5)
#define NOTE_D5 (NOTE_D0 + NOTE_OCTAVE*5)
#define NOTE_DS5 (NOTE_DS0 + NOTE_OCTAVE*5)
#define NOTE_E5 (NOTE_E0 + NOTE_OCTAVE*5)
#define NOTE_F5 (NOTE_F0 + NOTE_OCTAVE*5)
#define NOTE_FS5 (NOTE_FS0 + NOTE_OCTAVE*5)
#define NOTE_G5 (NOTE_G0 + NOTE_OCTAVE*5)
#define NOTE_GS5 (NOTE_GS0 + NOTE_OCTAVE*5)
#define NOTE_A5 (NOTE_A0 + NOTE_OCTAVE*5)
#define NOTE_AS5 (NOTE_AS0 + NOTE_OCTAVE*5)
#define NOTE_B5 (NOTE_B0 + NOTE_OCTAVE*5)

#define NOTE_C6 (NOTE_C0 + NOTE_OCTAVE*6)
#define NOTE_CS6 (NOTE_CS0 + NOTE_OCTAVE*6)
#define NOTE_D6 (NOTE_D0 + NOTE_OCTAVE*6)
#define NOTE_DS6 (NOTE_DS0 + NOTE_OCTAVE*6)
#define NOTE_E6 (NOTE_E0 + NOTE_OCTAVE*6)
#define NOTE_F6 (NOTE_F0 + NOTE_OCTAVE*6)
#define NOTE_FS6 (NOTE_FS0 + NOTE_OCTAVE*6)
#define NOTE_G6 (NOTE_G0 + NOTE_OCTAVE*6)
#define NOTE_GS6 (NOTE_GS0 + NOTE_OCTAVE*6)
#define NOTE_A6 (NOTE_A0 + NOTE_OCTAVE*6)
#define NOTE_AS6 (NOTE_AS0 + NOTE_OCTAVE*6)
#define NOTE_B6 (NOTE_B0 + NOTE_OCTAVE*6)

#define NOTE_C7 (NOTE_C0 + NOTE_OCTAVE*7)
#define NOTE_CS7 (NOTE_CS0 + NOTE_OCTAVE*7)
#define NOTE_D7 (NOTE_D0 + NOTE_OCTAVE*7)
#define NOTE_DS7 (NOTE_DS0 + NOTE_OCTAVE*7)
#define NOTE_E7 (NOTE_E0 + NOTE_OCTAVE*7)
#define NOTE_F7 (NOTE_F0 + NOTE_OCTAVE*7)
#define NOTE_FS7 (NOTE_FS0 + NOTE_OCTAVE*7)
#define NOTE_G7 (NOTE_G0 + NOTE_OCTAVE*7)
#define NOTE_GS7 (NOTE_GS0 + NOTE_OCTAVE*7)
#define NOTE_A7 (NOTE_A0 + NOTE_OCTAVE*7)
#define NOTE_AS7 (NOTE_AS0 + NOTE_OCTAVE*7)
#define NOTE_B7 (NOTE_B0 + NOTE_OCTAVE*7)

#define NOTE_C8 (NOTE_C0 + NOTE_OCTAVE*8)
#define NOTE_CS8 (NOTE_CS0 + NOTE_OCTAVE*8)
#define NOTE_D8 (NOTE_D0 + NOTE_OCTAVE*8)
#define NOTE_DS8 (NOTE_DS0 + NOTE_OCTAVE*8)
#define NOTE_E8 (NOTE_E0 + NOTE_OCTAVE*8)
#define NOTE_F8 (NOTE_F0 + NOTE_OCTAVE*8)
#define NOTE_FS8 (NOTE_FS0 + NOTE_OCTAVE*8)
#define NOTE_G8 (NOTE_G0 + NOTE_OCTAVE*8)
#define NOTE_GS8 (NOTE_GS0 + NOTE_OCTAVE*8)
#define NOTE_A8 (NOTE_A0 + NOTE_OCTAVE*8)
#define NOTE_AS8 (NOTE_AS0 + NOTE_OCTAVE*8)
#define NOTE_B8 (NOTE_B0 + NOTE_OCTAVE*8)

#define NOTE_C9 (NOTE_C0 + NOTE_OCTAVE*9)
#define NOTE_CS9 (NOTE_CS0 + NOTE_OCTAVE*9)
#define NOTE_D9 (NOTE_D0 + NOTE_OCTAVE*9)
#define NOTE_DS9 (NOTE_DS0 + NOTE_OCTAVE*9)
#define NOTE_E9 (NOTE_E0 + NOTE_OCTAVE*9)
#define NOTE_F9 (NOTE_F0 + NOTE_OCTAVE*9)
#define NOTE_FS9 (NOTE_FS0 + NOTE_OCTAVE*9)
#define NOTE_G9 (NOTE_G0 + NOTE_OCTAVE*9)
#define NOTE_GS9 (NOTE_GS0 + NOTE_OCTAVE*9)
#define NOTE_A9 (NOTE_A0 + NOTE_OCTAVE*9)
#define NOTE_16AS9 (NOTE_AS0 + NOTE_OCTAVE*9)
#define NOTE_B9 (NOTE_B0 + NOTE_OCTAVE*9)

// acid bassline 1?
// note format: pitch.w, interval.w (in TICKLEN), sustain.w (in ADSR_TICKLEN)
unsigned short song_[] =
{
   12*2,4*4,10*8
  ,12*2,4*8,10*8
  ,12*2,4*2,5*8
  ,12*2+2,4*2,5*8
  ,12*2,4*2,5*8
  ,12*2+2,4*2,5*8
  ,12*2,4*2,5*8
  ,12*2+2,4*4,7*8
  ,12*2,4*8,10*8
};

// industrial loop check
// note format: pitch.w, interval.w (in TICKLEN), sustain.w (in ADSR_TICKLEN)
unsigned short song__[] =
{
   12*1,  4*4,5*8
  ,12*1+1,4*1,2*8
  ,12*1+2,4*4,2*8
  ,12*1+1,4*1,2*8
  ,12*1+2,4*4,2*8
};


// 5 quarters?
// note format: pitch.w, interval.w (in TICKLEN), sustain.w (in ADSR_TICKLEN)
unsigned short song___[] =
{
   12*2,  4*4,5*8
  ,12*2+1,4*1,2*8
  ,12*2+2,4*4,2*8
  ,12*2+1,4*1,2*8
  ,12*2+2,4*4,2*8
  ,12*2+1,4*1,2*8
  ,12*2+2,4*3,2*8
  ,12*2+4,4*1,2*8
  ,12*2+3,4*9,4*8
};
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

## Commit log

2015-01-09 lfo button pin changed. introduced gpio debugging again.
2015-01-19 lfo speed for sample and hold.
2015-01-20 midi ccs for all 12 pot functions. vcf keyboard tracking + midi cc. lfo led with soft pwm.
2015-01-20 fixed lfo crap. addressing with signed offset where unsigned is passed. yep.
    [piggy_midv_newer.ino]
2015-01-20 lfo speed via midi now scaled correctly.
    [piggy_midv_newer.ino]
2015-01-25 fixed potstate behaviour. midi can now always interrupt it. pots can always override midi, and their initial behavior after reset is fixed. lfo led now optional (because of the background noise it ma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
    [piggy_midv_newer.ino]
2015-02-11 added calibration script for J unit.
2015-02-11 added lfo led disable featuring (hold down lfo button 3 seconds). added k unit calibration script.
2015-02-16 first version of the firmware that uses self-calibration. requires a trace (or patch wire) from vco buffer output to arduino pin 4.
2015-02-17 shortened calibration and also made it more reliable. boot now takes 3 seconds. parameters now have defaults. vcf env overflow bug fixed. lfo mode is sine wave, by default.
    [piggy_midv_newer.ino]
2015-07-24 potential fix for midi problems. all midi bytes are now handled by the statemachine, at least.
    [sawbench_v3.ino]
2018-11-04 hardware added
    [sawbench_analog_reva.brd, sawbench_analog_reva.sch, sawbench_digital_reva.brd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]

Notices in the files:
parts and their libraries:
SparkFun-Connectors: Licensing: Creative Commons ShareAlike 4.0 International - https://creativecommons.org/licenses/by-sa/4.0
